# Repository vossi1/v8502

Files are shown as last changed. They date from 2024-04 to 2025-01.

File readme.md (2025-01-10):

# V8502 - Replacement for a 8502 with a 6502  

**Copyright (c) 2024 Vossi - v.1**

**www.mos6502.net**

## License
This work is licensed under a Creative Commons Attribution-ShareAlike 4.0
International License. See [https://creativecommons.org/licenses/by-sa/4.0/](https://creativecommons.org/licenses/by-sa/4.0/).

v.1 initial (base is V6510 v.3)

**[Schematic](https://github.com/vossi1/v8502/blob/master/v8502_v1.png)**

**[Parts](https://github.com/vossi1/v8502/blob/master/parts.txt)**

**CPLD-Firmware:** The .JED file can be uploaded with a JTAG-SMT2 Xilinx programmer (China) and [xc3sprog](https://xc3sprog.sourceforge.net/)

:exclamation: **BEWARE: I got good CPLD's from China, but there are some XC9572XL FAKES out there!**

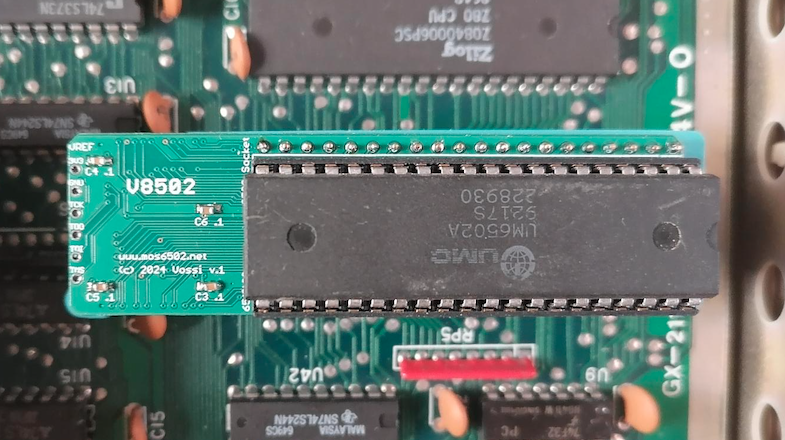
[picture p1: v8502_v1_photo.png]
V8502


:white_check_mark: **Tested successfully  with a UMC 6502A in my C128 & C128D-CR::**

- Risen from the Oblivion VIC
- Risen from the Oblivion VDC
- CPM VIC mode
- CPM VDC 80 column mode
- GEOS VIC mode with REU 1764, Mouse
- GEOS VDC mode with REU 1764, Mouse
- C128 Diagnostic cartridge
- Elite 128
- Sonic with REU 1764 c64 mode
- Galaxian cartridge C64 mode
- Blue Max from disk C64 mode
- Basic lesson loaded from tape
- SD2IEC with FB64 & FB128

**For a WDC 65C02 you have to cut the small trace in the other solder jumper.**

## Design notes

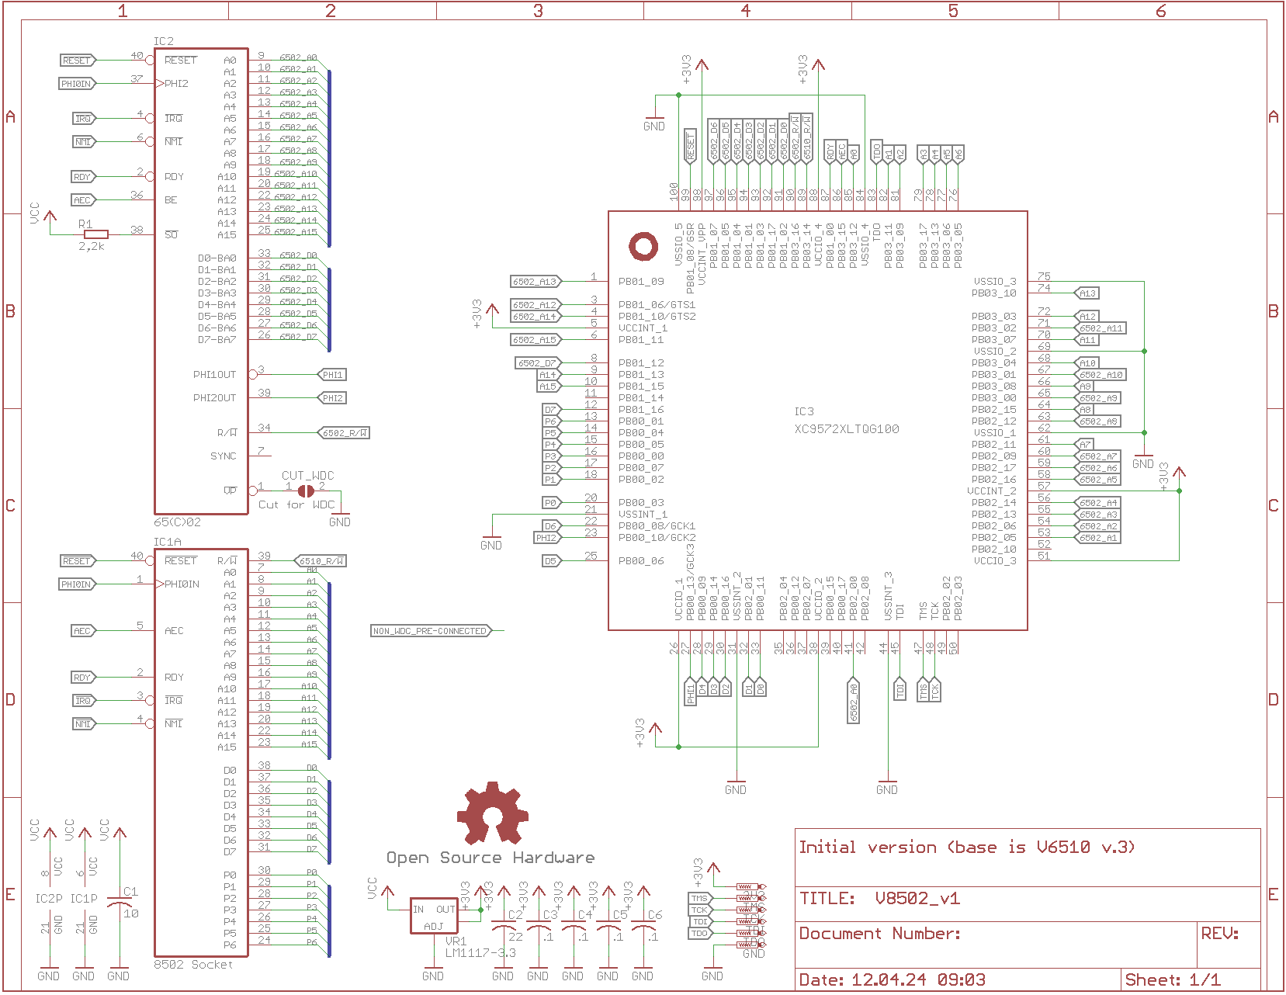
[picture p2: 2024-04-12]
v8502_v1.png

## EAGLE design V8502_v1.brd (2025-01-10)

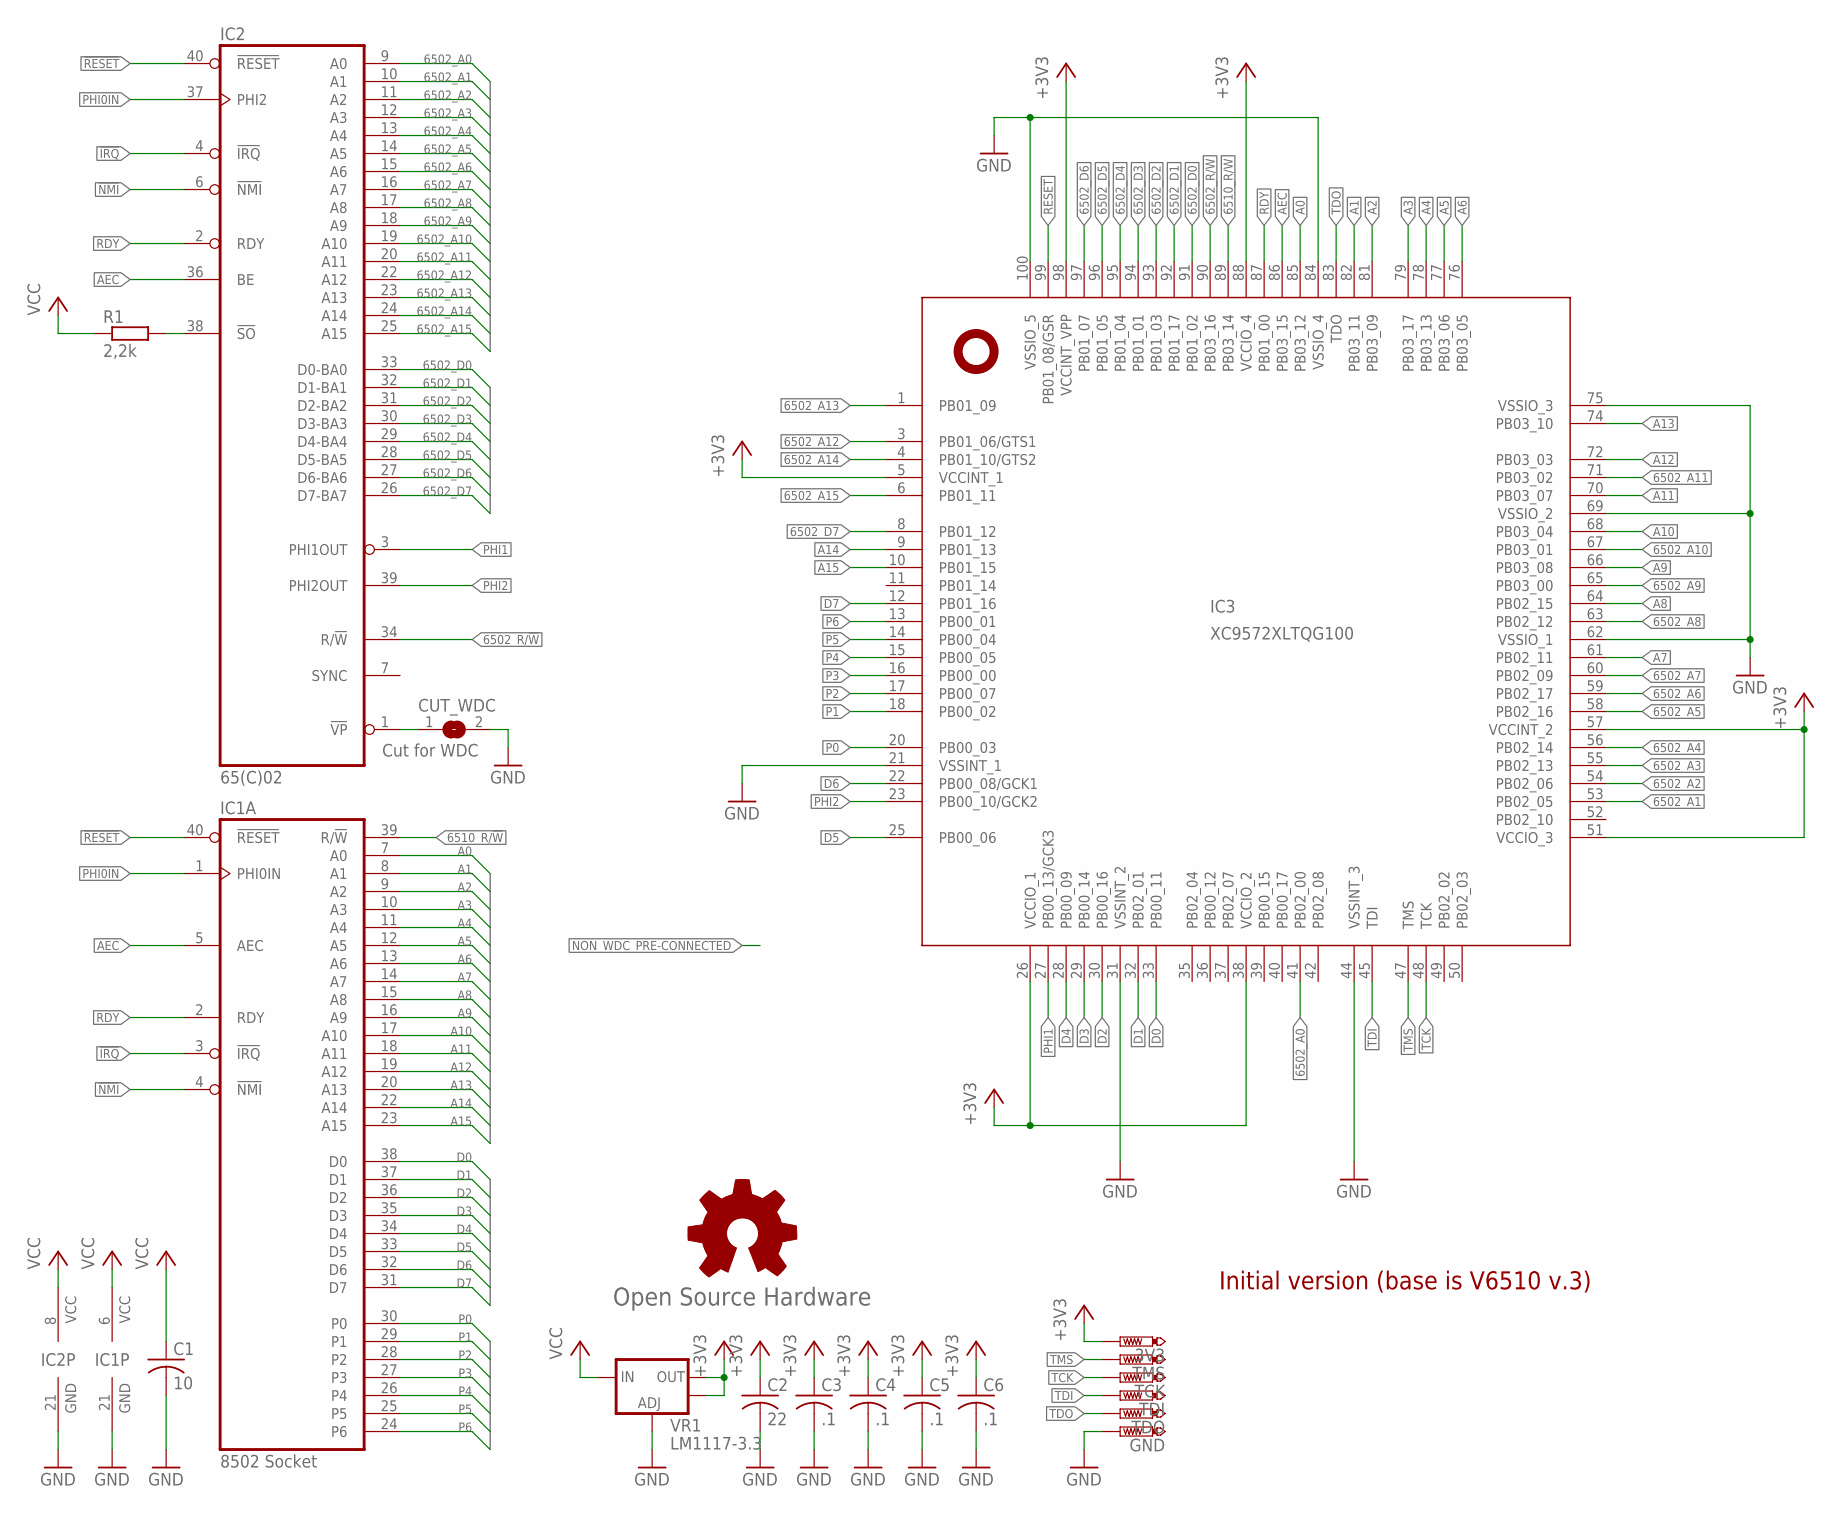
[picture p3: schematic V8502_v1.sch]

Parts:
3V3: PTR1TP08R; TP08R
C1: 10; C0805
C2: 22; C0805
C3, C4, C5, C6: .1; C0603
CUT_WDC: Cut for WDC; SJ
GND: PTR1TP08R; TP08R
GOLD_ORB_SM1: Open Source Hardware; OSHW_5MM
IC1: 8502 Socket; DIL40-ROUNDPAD
IC2: 65(C)02; DIL40-ROUNDPAD
IC3: XC9572XLTQG100; TQFP100
R1: 2,2k; 0603
TCK: PTR1TP08R; TP08R
TDI: PTR1TP08R; TP08R
TDO: PTR1TP08R; TP08R
TMS: PTR1TP08R; TP08R
VR1: LM1117-3.3; SOT223

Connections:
6502_A0: IC2.9 (A0), IC3.41 (PB02_00)
6502_A1: IC2.10 (A1), IC3.53 (PB02_05)
6502_A2: IC2.11 (A2), IC3.54 (PB02_06)
6502_A3: IC2.12 (A3), IC3.55 (PB02_13)
6502_A4: IC2.13 (A4), IC3.56 (PB02_14)
6502_A5: IC2.14 (A5), IC3.58 (PB02_16)
6502_A6: IC2.15 (A6), IC3.59 (PB02_17)
6502_A7: IC2.16 (A7), IC3.60 (PB02_09)
6502_A8: IC2.17 (A8), IC3.63 (PB02_12)
6502_A9: IC2.18 (A9), IC3.65 (PB03_00)
6502_A10: IC2.19 (A10), IC3.67 (PB03_01)
6502_A11: IC2.20 (A11), IC3.71 (PB03_02)
6502_A12: IC2.22 (A12), IC3.3 (PB01_06/GTS1)
6502_A13: IC2.23 (A13), IC3.1 (PB01_09)
6502_A14: IC2.24 (A14), IC3.4 (PB01_10/GTS2)
6502_A15: IC2.25 (A15), IC3.6 (PB01_11)
6502_D0: IC2.33 (D0-BA0), IC3.91 (PB01_02)
6502_D1: IC2.32 (D1-BA1), IC3.92 (PB01_17)
6502_D2: IC2.31 (D2-BA2), IC3.93 (PB01_03)
6502_D3: IC2.30 (D3-BA3), IC3.94 (PB01_01)
6502_D4: IC2.29 (D4-BA4), IC3.95 (PB01_04)
6502_D5: IC2.28 (D5-BA5), IC3.96 (PB01_05)
6502_D6: IC2.27 (D6-BA6), IC3.97 (PB01_07)
6502_D7: IC2.26 (D7-BA7), IC3.8 (PB01_12)
6502_R/!W: IC2.34 (R/!W), IC3.90 (PB03_16)
6502_VSS: CUT_WDC.1, IC2.1 (!VP)
6510_R/!W: IC1.39 (R/!W), IC3.89 (PB03_14)
!IRQ: IC1.3 (!IRQ), IC2.4 (!IRQ)
!NMI: IC1.4 (!NMI), IC2.6 (!NMI)
!RESET: IC1.40 (!RESET), IC2.40 (!RESET), IC3.99 (PB01_08/GSR)
!SO: IC2.38 (!SO), R1.2
+3V3: 3V3.TP, C2.1, C3.1, C4.1, C5.1, C6.1, IC3.5 (VCCINT_1), IC3.26 (VCCIO_1), IC3.38 (VCCIO_2), IC3.51 (VCCIO_3), IC3.57 (VCCINT_2), IC3.88 (VCCIO_4), IC3.98 (VCCINT_VPP), VR1.2 (OUT), VR1.4 (OUT)
A0: IC1.7 (A0), IC3.85 (PB03_12)
A1: IC1.8 (A1), IC3.82 (PB03_11)
A2: IC1.9 (A2), IC3.81 (PB03_09)
A3: IC1.10 (A3), IC3.79 (PB03_17)
A4: IC1.11 (A4), IC3.78 (PB03_13)
A5: IC1.12 (A5), IC3.77 (PB03_06)
A6: IC1.13 (A6), IC3.76 (PB03_05)
A7: IC1.14 (A7), IC3.61 (PB02_11)
A8: IC1.15 (A8), IC3.64 (PB02_15)
A9: IC1.16 (A9), IC3.66 (PB03_08)
A10: IC1.17 (A10), IC3.68 (PB03_04)
A11: IC1.18 (A11), IC3.70 (PB03_07)
A12: IC1.19 (A12), IC3.72 (PB03_03)
A13: IC1.20 (A13), IC3.74 (PB03_10)
A14: IC1.22 (A14), IC3.9 (PB01_13)
A15: IC1.23 (A15), IC3.10 (PB01_15)
AEC: IC1.5 (AEC), IC2.36 (BE), IC3.86 (PB03_15)
D0: IC1.38 (D0), IC3.33 (PB00_11)
D1: IC1.37 (D1), IC3.32 (PB02_01)
D2: IC1.36 (D2), IC3.30 (PB00_16)
D3: IC1.35 (D3), IC3.29 (PB00_14)
D4: IC1.34 (D4), IC3.28 (PB00_09)
D5: IC1.33 (D5), IC3.25 (PB00_06)
D6: IC1.32 (D6), IC3.22 (PB00_08/GCK1)
D7: IC1.31 (D7), IC3.12 (PB01_16)
GND: C1.2, C2.2, C3.2, C4.2, C5.2, C6.2, CUT_WDC.2, GND.TP, IC1.21 (GND), IC2.21 (GND), IC3.21 (VSSINT_1), IC3.31 (VSSINT_2), IC3.44 (VSSINT_3), IC3.62 (VSSIO_1), IC3.69 (VSSIO_2), IC3.75 (VSSIO_3), IC3.84 (VSSIO_4), IC3.100 (VSSIO_5), VR1.1 (ADJ)
P0: IC1.30 (P0), IC3.20 (PB00_03)
P1: IC1.29 (P1), IC3.18 (PB00_02)
P2: IC1.28 (P2), IC3.17 (PB00_07)
P3: IC1.27 (P3), IC3.16 (PB00_00)
P4: IC1.26 (P4), IC3.15 (PB00_05)
P5: IC1.25 (P5), IC3.14 (PB00_04)
P6: IC1.24 (P6), IC3.13 (PB00_01)
PHI0IN: IC1.1 (PHI0IN), IC2.37 (PHI2)
PHI1: IC2.3 (PHI1OUT), IC3.27 (PB00_13/GCK3)
PHI2: IC2.39 (PHI2OUT), IC3.23 (PB00_10/GCK2)
RDY: IC1.2 (RDY), IC2.2 (RDY), IC3.87 (PB01_00)
TCK: IC3.48 (TCK), TCK.TP
TDI: IC3.45 (TDI), TDI.TP
TDO: IC3.83 (TDO), TDO.TP
TMS: IC3.47 (TMS), TMS.TP
VCC: C1.1, IC1.6 (VCC), IC2.8 (VCC), R1.1, VR1.3 (IN)

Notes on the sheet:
Initial version (base is V6510 v.3)

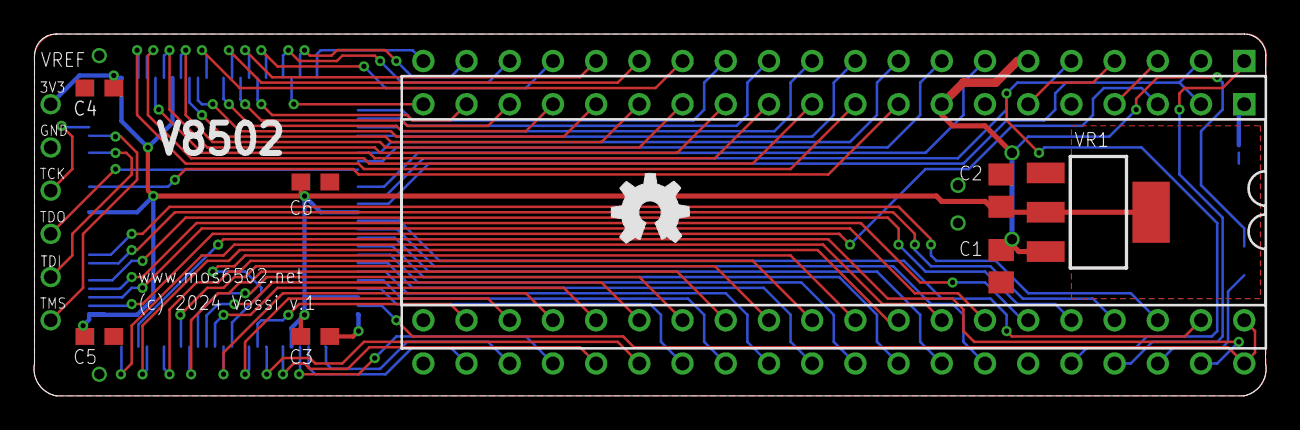
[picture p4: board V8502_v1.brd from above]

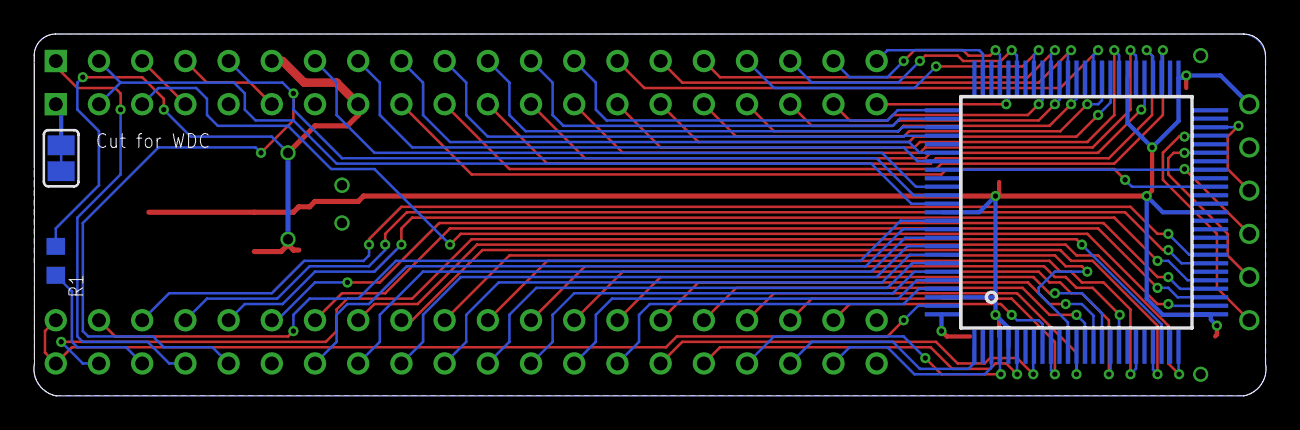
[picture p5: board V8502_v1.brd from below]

Board: 2 copper layers, 72.4 x 21.3 mm, 19 parts (3 on the bottom side), 74 nets.

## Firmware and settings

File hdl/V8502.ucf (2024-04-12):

#NET "rdy"  LOC = "P87"  ; 

#PACE: Start of Constraints generated by PACE

#PACE: Start of PACE I/O Pin Assignments
NET "_reset"  LOC = "P99"  ; 
NET "address_6502<0>"  LOC = "P41"  ; 
NET "address_6502<10>"  LOC = "P67"  ; 
NET "address_6502<11>"  LOC = "P71"  ; 
NET "address_6502<12>"  LOC = "P3"  ; 
NET "address_6502<13>"  LOC = "P1"  ; 
NET "address_6502<14>"  LOC = "P4"  ; 
NET "address_6502<15>"  LOC = "P6"  ; 
NET "address_6502<1>"  LOC = "P53"  ; 
NET "address_6502<2>"  LOC = "P54"  ; 
NET "address_6502<3>"  LOC = "P55"  ; 
NET "address_6502<4>"  LOC = "P56"  ; 
NET "address_6502<5>"  LOC = "P58"  ; 
NET "address_6502<6>"  LOC = "P59"  ; 
NET "address_6502<7>"  LOC = "P60"  ; 
NET "address_6502<8>"  LOC = "P63"  ; 
NET "address_6502<9>"  LOC = "P65"  ; 
NET "address_8502<0>"  LOC = "P85"  ; 
NET "address_8502<10>"  LOC = "P68"  ; 
NET "address_8502<11>"  LOC = "P70"  ; 
NET "address_8502<12>"  LOC = "P72"  ; 
NET "address_8502<13>"  LOC = "P74"  ; 
NET "address_8502<14>"  LOC = "P9"  ; 
NET "address_8502<15>"  LOC = "P10"  ; 
NET "address_8502<1>"  LOC = "P82"  ; 
NET "address_8502<2>"  LOC = "P81"  ; 
NET "address_8502<3>"  LOC = "P79"  ; 
NET "address_8502<4>"  LOC = "P78"  ; 
NET "address_8502<5>"  LOC = "P77"  ; 
NET "address_8502<6>"  LOC = "P76"  ; 
NET "address_8502<7>"  LOC = "P61"  ; 
NET "address_8502<8>"  LOC = "P64"  ; 
NET "address_8502<9>"  LOC = "P66"  ; 
NET "aec"  LOC = "P86"  ; 
NET "data_6502<0>"  LOC = "P91"  ; 
NET "data_6502<1>"  LOC = "P92"  ; 
NET "data_6502<2>"  LOC = "P93"  ; 
NET "data_6502<3>"  LOC = "P94"  ; 
NET "data_6502<4>"  LOC = "P95"  ; 
NET "data_6502<5>"  LOC = "P96"  ; 
NET "data_6502<6>"  LOC = "P97"  ; 
NET "data_6502<7>"  LOC = "P8"  ; 
NET "data_8502<0>"  LOC = "P33"  ; 
NET "data_8502<1>"  LOC = "P32"  ; 
NET "data_8502<2>"  LOC = "P30"  ; 
NET "data_8502<3>"  LOC = "P29"  ; 
NET "data_8502<4>"  LOC = "P28"  ; 
NET "data_8502<5>"  LOC = "P25"  ; 
NET "data_8502<6>"  LOC = "P22"  ; 
NET "data_8502<7>"  LOC = "P12"  ;
NET "ioport<0>"  LOC = "P20"  ;
NET "ioport<1>"  LOC = "P18"  ;
NET "ioport<2>"  LOC = "P17"  ;
NET "ioport<3>"  LOC = "P16"  ;
NET "ioport<4>"  LOC = "P15"  ;
NET "ioport<5>"  LOC = "P14"  ;
NET "ioport<6>"  LOC = "P13"  ;
NET "phi1"  LOC = "P27"  ; 
NET "phi2"  LOC = "P23"  ; 
NET "r_w_6502"  LOC = "P90"  ; 
NET "r_w_8502"  LOC = "P89"  ; 

#PACE: Start of PACE Area Constraints

#PACE: Start of PACE Prohibit Constraints

#PACE: End of Constraints generated by PACE

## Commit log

2024-04-12 initial version - currently untested
2025-01-10 added eagle files
    [V8502_v1.brd, V8502_v1.sch]

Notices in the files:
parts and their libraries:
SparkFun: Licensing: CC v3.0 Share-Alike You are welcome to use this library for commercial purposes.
